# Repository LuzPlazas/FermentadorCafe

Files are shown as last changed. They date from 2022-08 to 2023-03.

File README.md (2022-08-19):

# FermentadorCafe
Códigos asociados al monitor de fermentación de café
-----------

DESARROLLO DE UN SISTEMA PARA EL MONITOREO INTELIGENTE DEL PROCESO DE FERMENTACIÓN DEL CAFÉ 

LUZ ADRIANA PLAZAS PEMBERTHY
CÓDIGO 2190651

UNIVERSIDAD AUTÓNOMA DE OCCIDENTE
2022

------------------------------
Código generado en el desarrollo de un sistema de monitoreo inteligente del proceso de fermentación del café para facilitarle al caficultor la producción de diferentes perfiles de café.

* Se encuentra el firmware para Arduino para la lectura y procesamiento de sensores.
* Se encuentra el software para Raspberry desarrollado en python para almacenamiento y análisis de datos.
* Se encuentran los códigos para entrenamiento de los modelos de aprendizaje automático y los dataset asociados en formato csv.

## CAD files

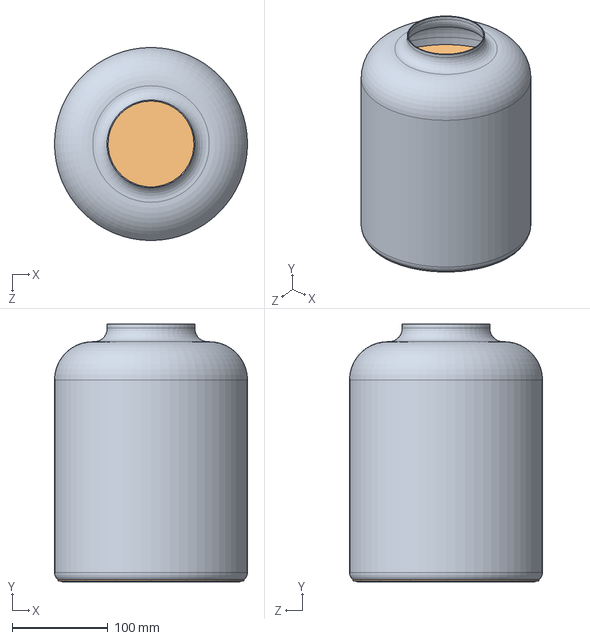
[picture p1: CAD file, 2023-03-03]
MF-A002-V1/MF-E001.SLDASM
202.0 x 270.0 x 202.0 mm
e1

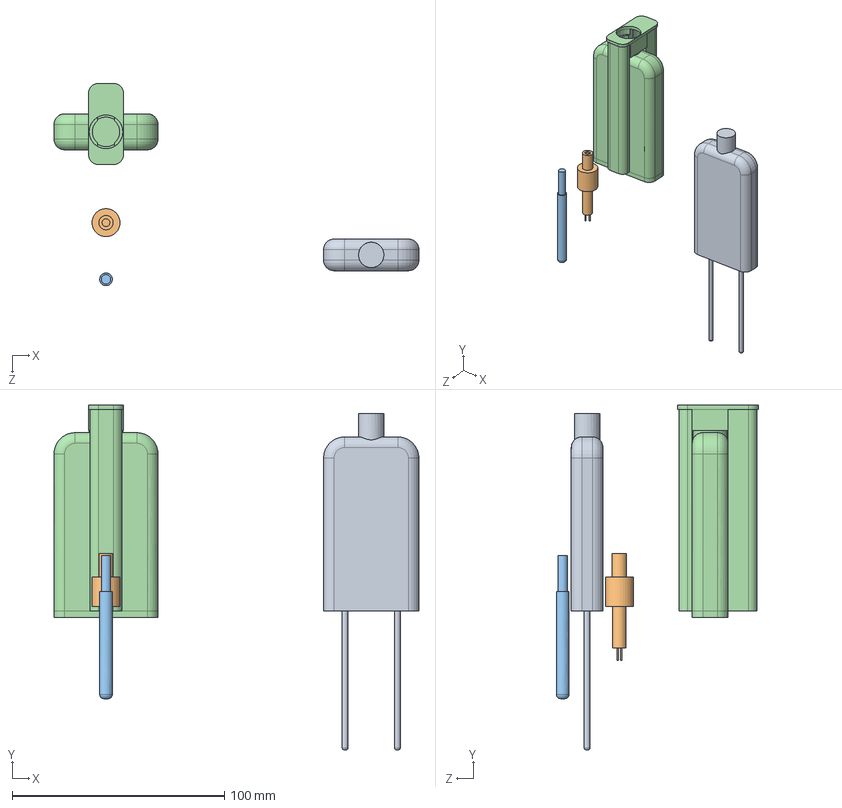
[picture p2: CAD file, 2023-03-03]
MF-A002-V1/Assem3.SLDASM
171.9 x 162.5 x 95.3 mm
MF-P009
MF-P010
MF-P011

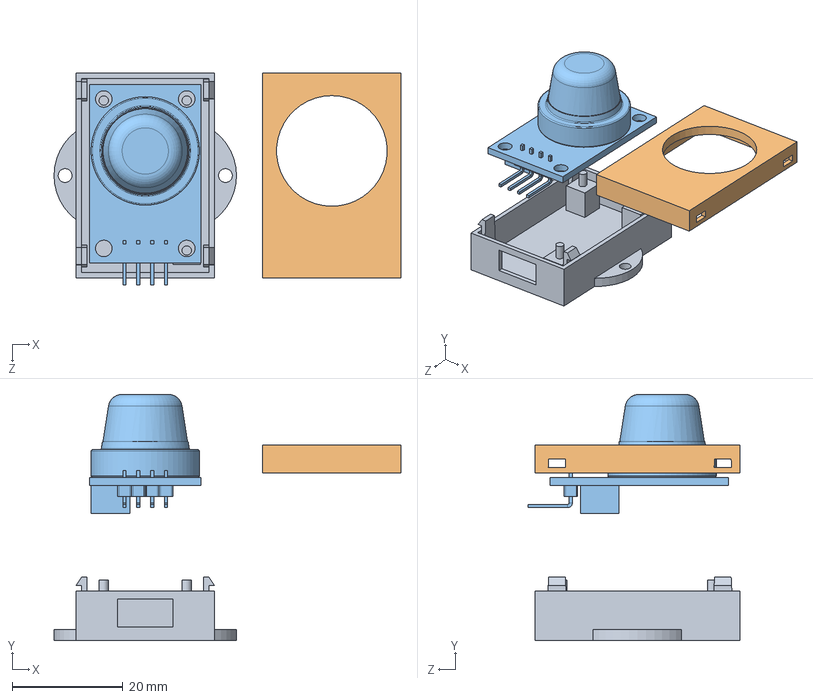
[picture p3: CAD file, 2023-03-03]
MF-A002-V1/s2.SLDASM
62.7 x 44.5 x 38.3 mm
MF-P022
MF-P023
MF-P020

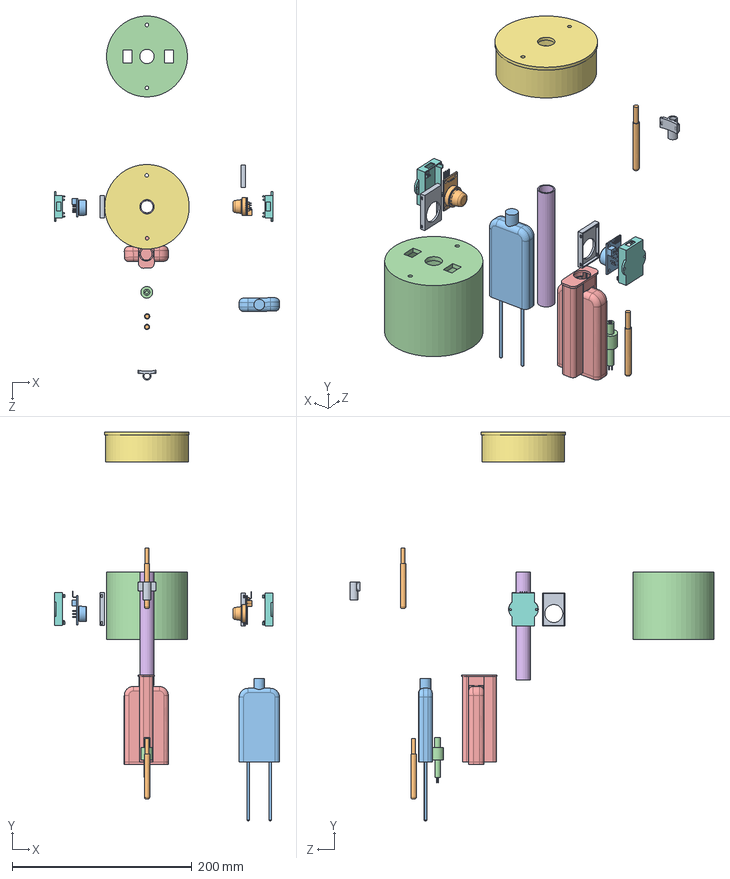
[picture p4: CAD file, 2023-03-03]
MF-A002-V1/MF-B001.SLDASM
250.4 x 432.3 x 404.8 mm
MF-P019b
MF-P011 x 2
MF-P009
MF-P010
MF-P022 x 2
MF-P023 x 2
MF-P020
MF-P021
Part1-B

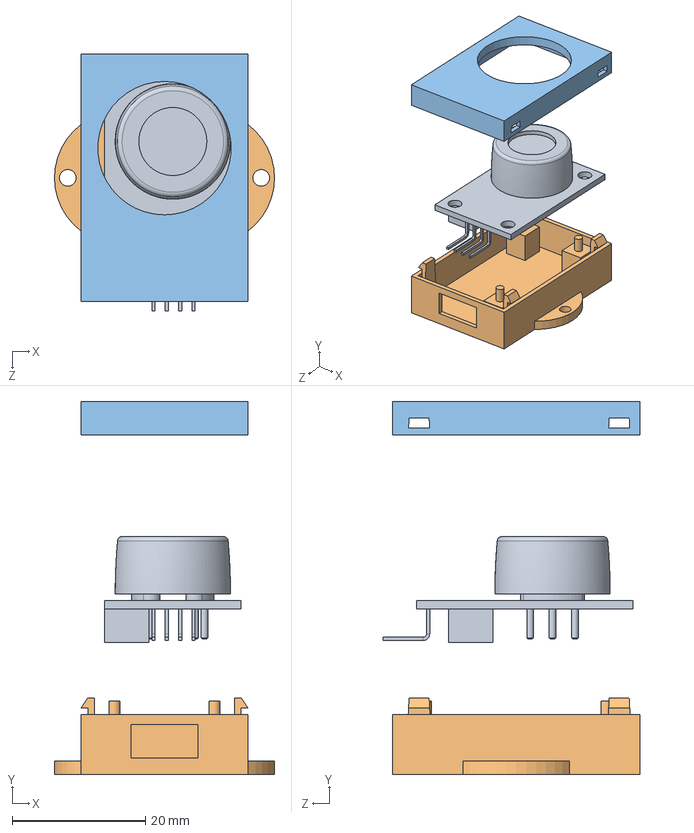
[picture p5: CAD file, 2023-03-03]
MF-A002-V1/s1.SLDASM
33.0 x 55.9 x 38.5 mm
MF-P021
MF-P022
MF-P023

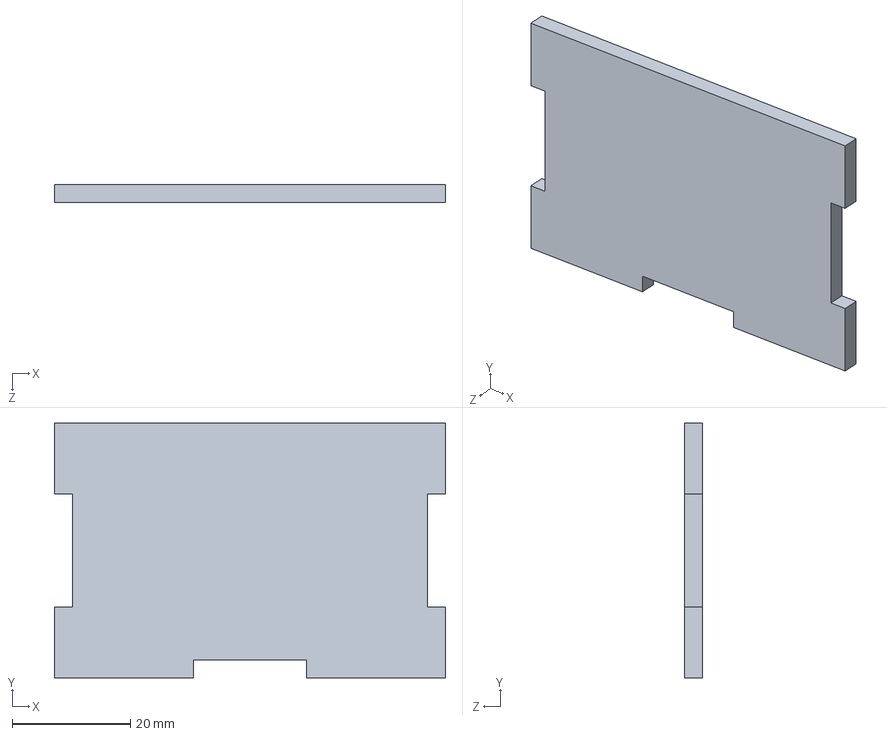
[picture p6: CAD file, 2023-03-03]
MF-A002-V1/front.SLDPRT
66.0 x 43.0 x 3.00 mm

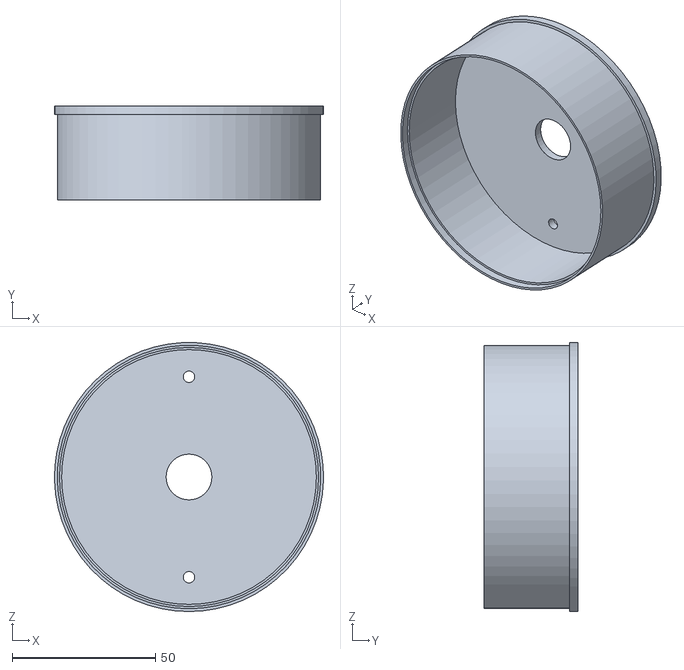
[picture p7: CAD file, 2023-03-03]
MF-A002-V1/Imprimir/Part4.STL
94.0 x 33.0 x 94.0

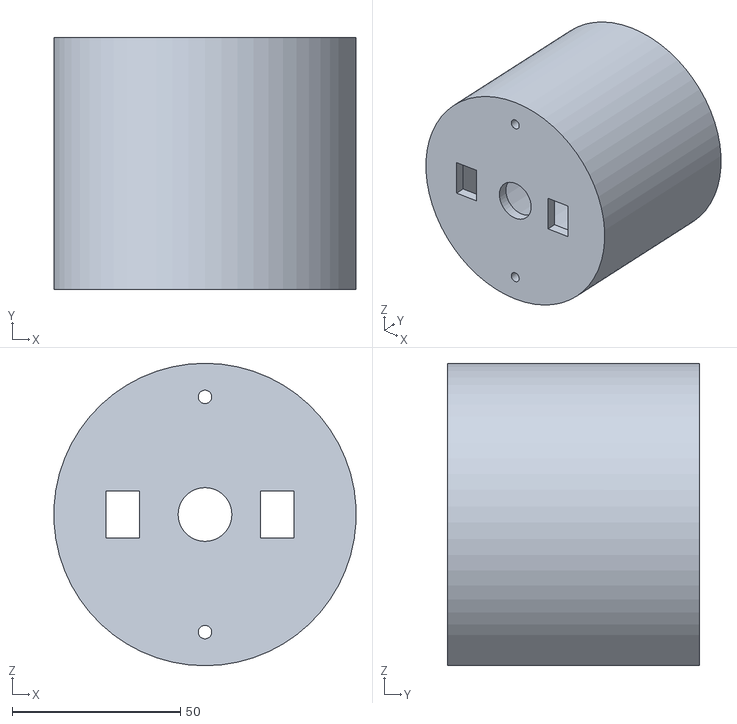
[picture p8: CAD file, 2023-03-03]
MF-A002-V1/Imprimir/Part1-B.STL
89.9 x 75.0 x 90.0

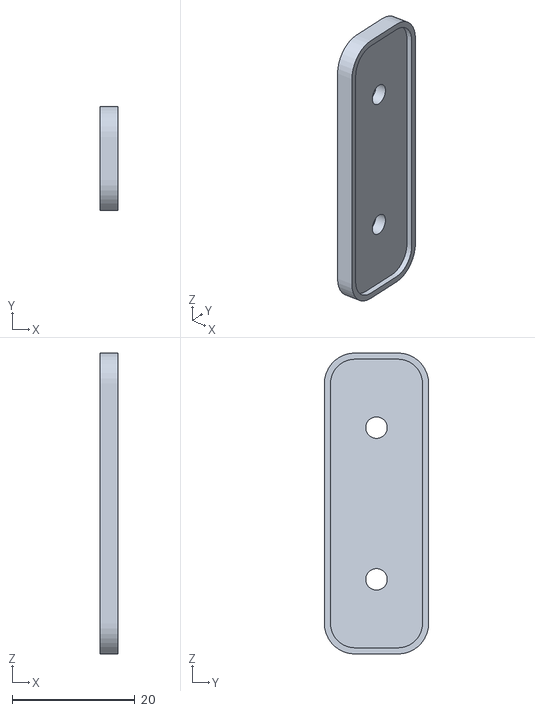
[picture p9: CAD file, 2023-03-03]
MF-A002-V1/Imprimir/Part6-inf.STL
3.00 x 17.0 x 49.0

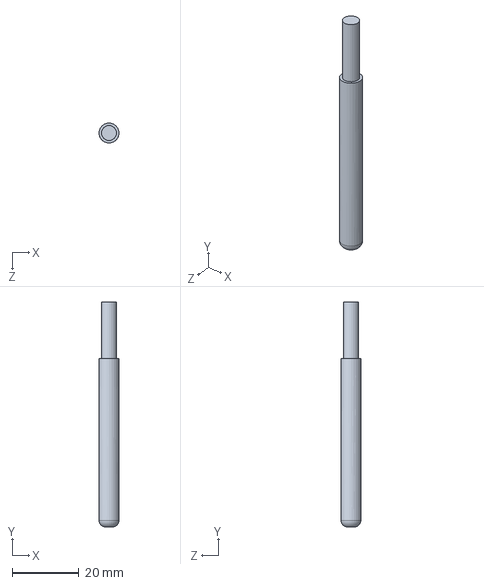
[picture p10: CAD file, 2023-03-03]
MF-A002-V1/MF-P011.SLDPRT
6.00 x 67.5 x 6.00 mm

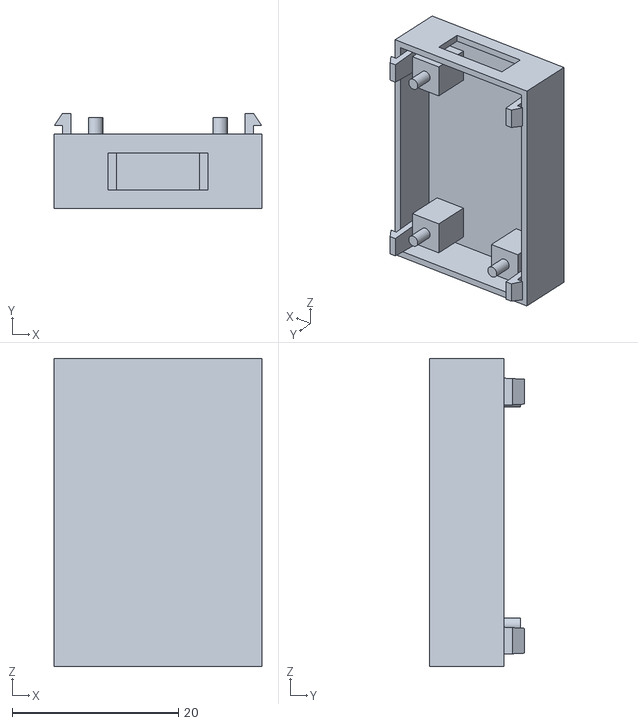
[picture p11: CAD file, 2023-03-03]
MF-A002-V1/Imprimir/MF-P022.STL
25.0 x 11.5 x 37.1

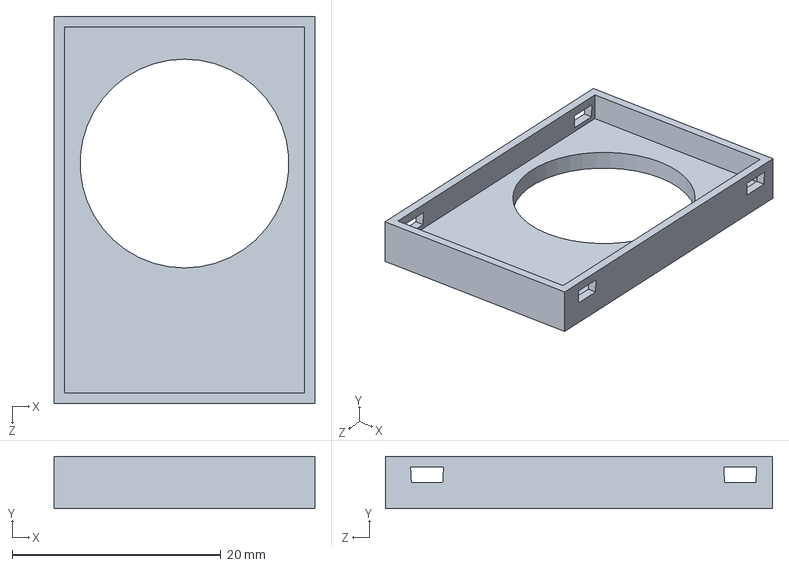
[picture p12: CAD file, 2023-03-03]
MF-A002-V1/MF-P023.SLDPRT
25.0 x 5.00 x 37.1 mm

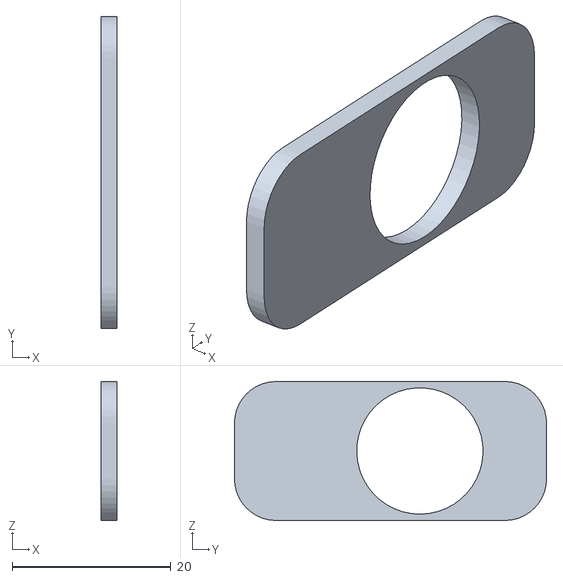
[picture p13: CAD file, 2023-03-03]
MF-A002-V1/Imprimir/Part6-sup.STL
2.00 x 39.3 x 17.5

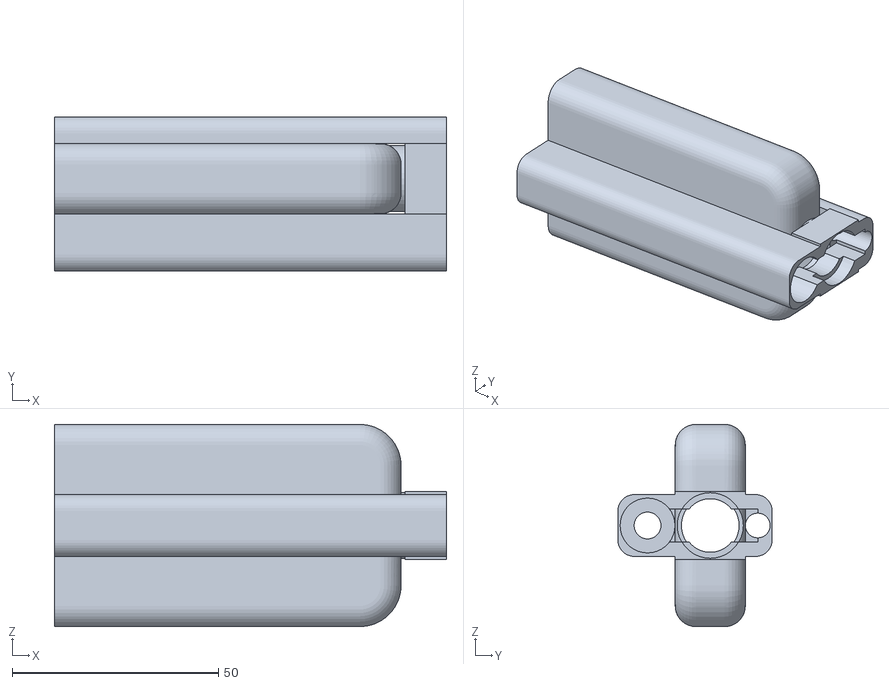
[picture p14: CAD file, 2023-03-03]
MF-A002-V1/Imprimir/Part6-cuerpo.STL
95.0 x 37.4 x 49.0

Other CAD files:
MF-A002-V1/Part4.SLDPRT
MF-A002-V1/MF-P008.SLDPRT
MF-A002-V1/Imprimir/MF-P023.STL
MF-A002-V1/MF-P013-v2.SLDPRT
MF-A002-V1/Imprimir/Part5.STL
MF-A002-V1/MF-P007.SLDPRT
MF-A002-V1/MF-P009.SLDPRT
MF-A002-V1/MF-P010.SLDPRT
MF-A002-V1/MF-P012.SLDPRT
MF-A002-V1/MF-P014.SLDPRT
MF-A002-V1/MF-P015.SLDPRT
MF-A002-V1/MF-P019.SLDPRT
MF-A002-V1/MF-P019b.SLDPRT
MF-A002-V1/MF-P020.SLDPRT
MF-A002-V1/MF-P021.SLDPRT
MF-A002-V1/MF-P022.SLDPRT
MF-A002-V1/Part1-B.SLDPRT
MF-A002-V1/Part1.SLDPRT
MF-A002-V1/Part2.SLDPRT
MF-A002-V1/Part5.SLDPRT
MF-A002-V1/Part6.SLDPRT
MF-A002-V1/botom.SLDPRT
MF-A002-V1/e1.SLDPRT
MF-A002-V1/lock.SLDPRT
MF-A002-V1/right.SLDPRT
MF-A002-V1/tapa.SLDPRT

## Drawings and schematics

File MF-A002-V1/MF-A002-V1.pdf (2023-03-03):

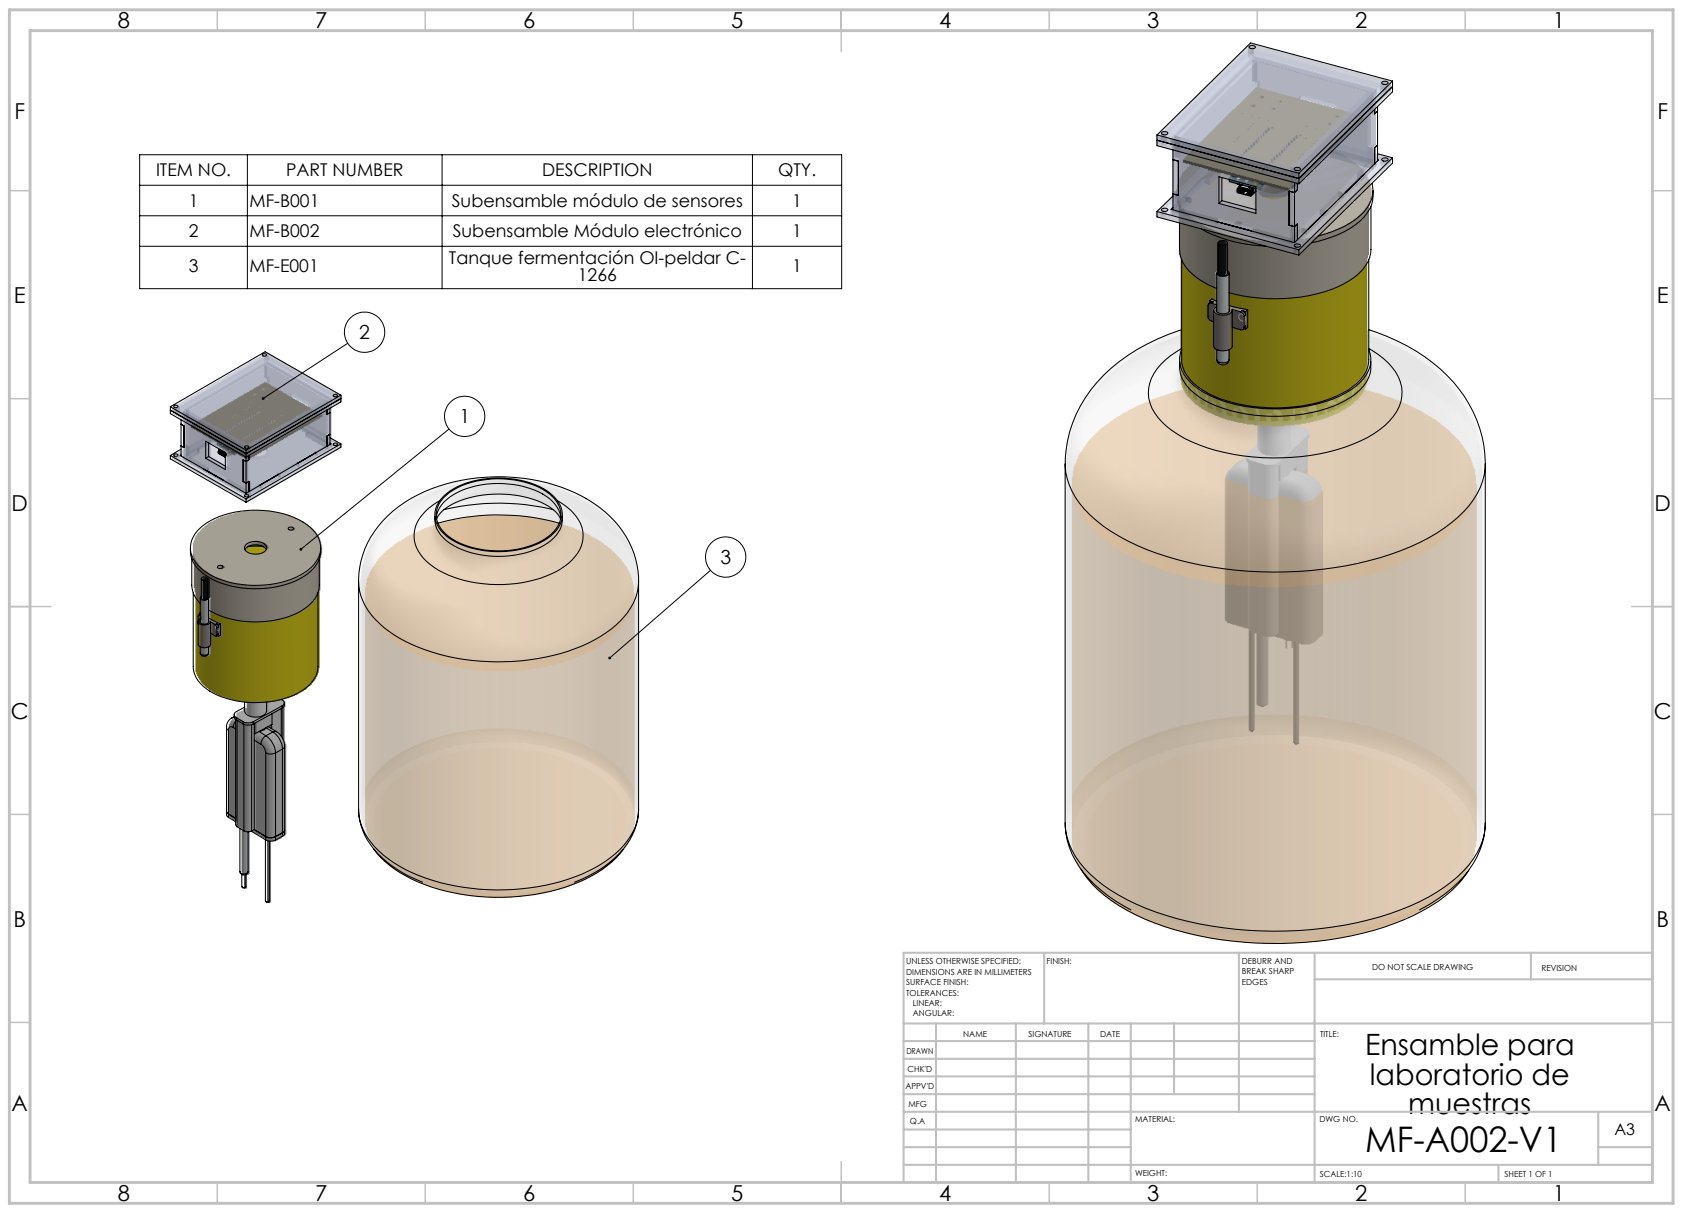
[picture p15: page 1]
FINISH:; DEBURR AND; BREAK SHARP; DO NOT SCALE DRAWING; REVISION; SCALE:1:10; SHEET 1 OF 1

ITEM NO. | PART NUMBER | DESCRIPTION | QTY.
1 | MF-B001 | Subensamble módulo de sensores | 1
2 | MF-B002 | Subensamble Módulo electrónico | 1
3 | MF-E001 | Tanque fermentación OI-peldar C-1266 | 1

UNLESS OTHERWISE SPECIFIED:
DIMENSIONS ARE IN MILLIMETERS
SURFACE FINISH:
TOLERANCES:
LINEAR:
ANGULAR:

NAME | SIGNATURE | DATE | | | | Ensamble para TITLE: laboratorio de muestras

DRAWN
CHK'D
APPV'D
MFG
Q.A | | | | MATERIAL: | DWG NO. MF-A002-V1 | A3

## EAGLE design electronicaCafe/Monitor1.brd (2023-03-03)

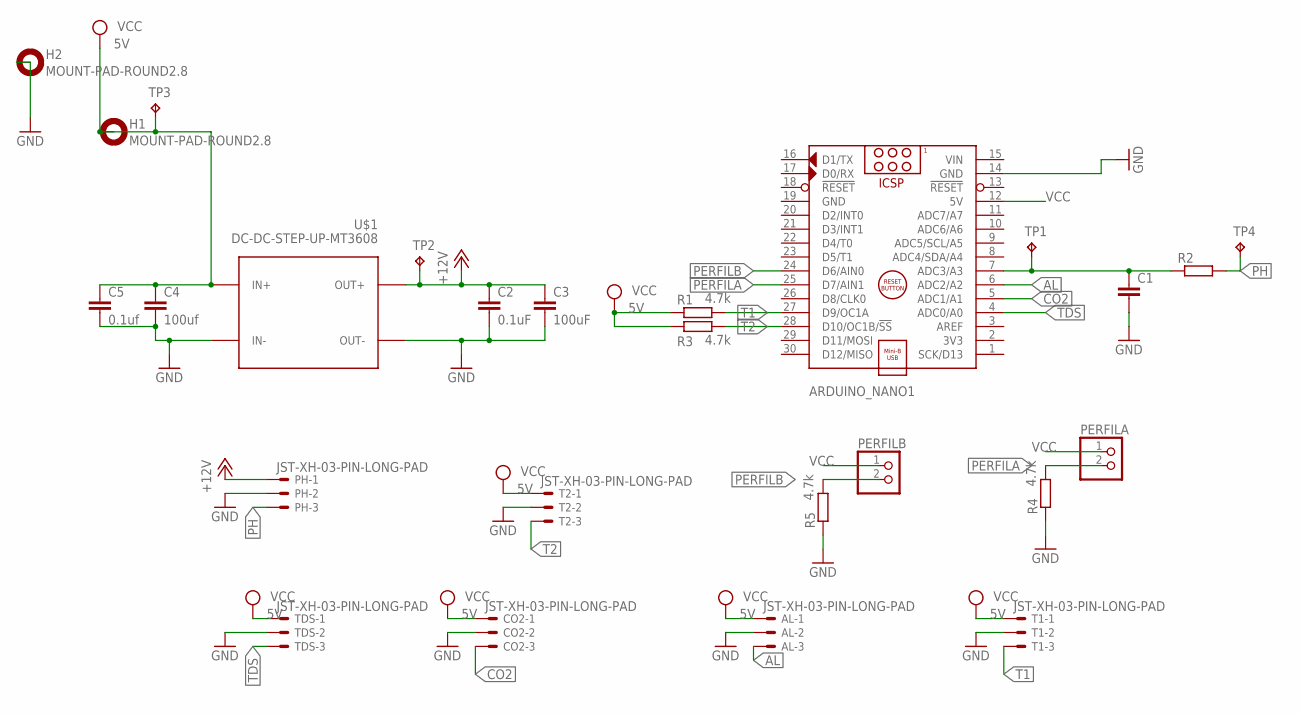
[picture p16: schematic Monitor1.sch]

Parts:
AL: JST-XH-03-PIN-LONG-PAD; JST-XH-03-PACKAGE-LONG-PAD
ARDUINO_NANO1: ARDUINO_NANO
C1: C-EU050-030X075; C050-030X075
C2: 0.1uF; C050-030X075
C3: 100uF; C050-045X075
C4: 100uf; C050-045X075
C5: 0.1uf; C050-030X075
CO2: JST-XH-03-PIN-LONG-PAD; JST-XH-03-PACKAGE-LONG-PAD
H1, H2: MOUNT-PAD-ROUND2.8; 2,8-PAD
PERFILA: PINHD-1X2; 1X02
PERFILB: PINHD-1X2; 1X02
PH: JST-XH-03-PIN-LONG-PAD; JST-XH-03-PACKAGE-LONG-PAD
R1, R3, R4, R5: 4.7k; 0309/10
R2: R-EU_0309/10; 0309/10
T1, T2: JST-XH-03-PIN-LONG-PAD; JST-XH-03-PACKAGE-LONG-PAD
TDS: JST-XH-03-PIN-LONG-PAD; JST-XH-03-PACKAGE-LONG-PAD
TP1, TP2, TP3, TP4: TPPAD1-13; P1-13
U$1: DC-DC-STEP-UP-MT3608

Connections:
+12V: C2.1, C3.1, PH.1, TP2.TP, U$1.OUT+
AL: AL.3, ARDUINO_NANO1.6 (ADC2/A2)
CO2: ARDUINO_NANO1.5 (ADC1/A1), CO2.3
GND: AL.2, ARDUINO_NANO1.14 (GND), ARDUINO_NANO1.19 (GND), C1.2, C2.2, C3.2, C4.2, C5.2, CO2.2, H2.B2,8, PH.2, R4.1, R5.1, T1.2, T2.2, TDS.2, U$1.IN-, U$1.OUT-
unnamed: ARDUINO_NANO1.7 (ADC3/A3), C1.1, R2.1, TP1.TP
PERFILA: ARDUINO_NANO1.25 (D7/AIN1), PERFILA.2, R4.2
PERFILB: ARDUINO_NANO1.24 (D6/AIN0), PERFILB.2, R5.2
PH: PH.3, R2.2, TP4.TP
T1: ARDUINO_NANO1.27 (D9/OC1A), R1.2, T1.3
T2: ARDUINO_NANO1.28 (D10/OC1B/!SS), R3.2, T2.3
TDS: ARDUINO_NANO1.4 (ADC0/A0), TDS.3
VCC: AL.1, ARDUINO_NANO1.12 (5V), C4.1, C5.1, CO2.1, H1.B2,8, PERFILA.1, PERFILB.1, R1.1, R3.1, T1.1, T2.1, TDS.1, TP3.TP, U$1.IN+
VIN: ARDUINO_NANO1.15 (VIN)

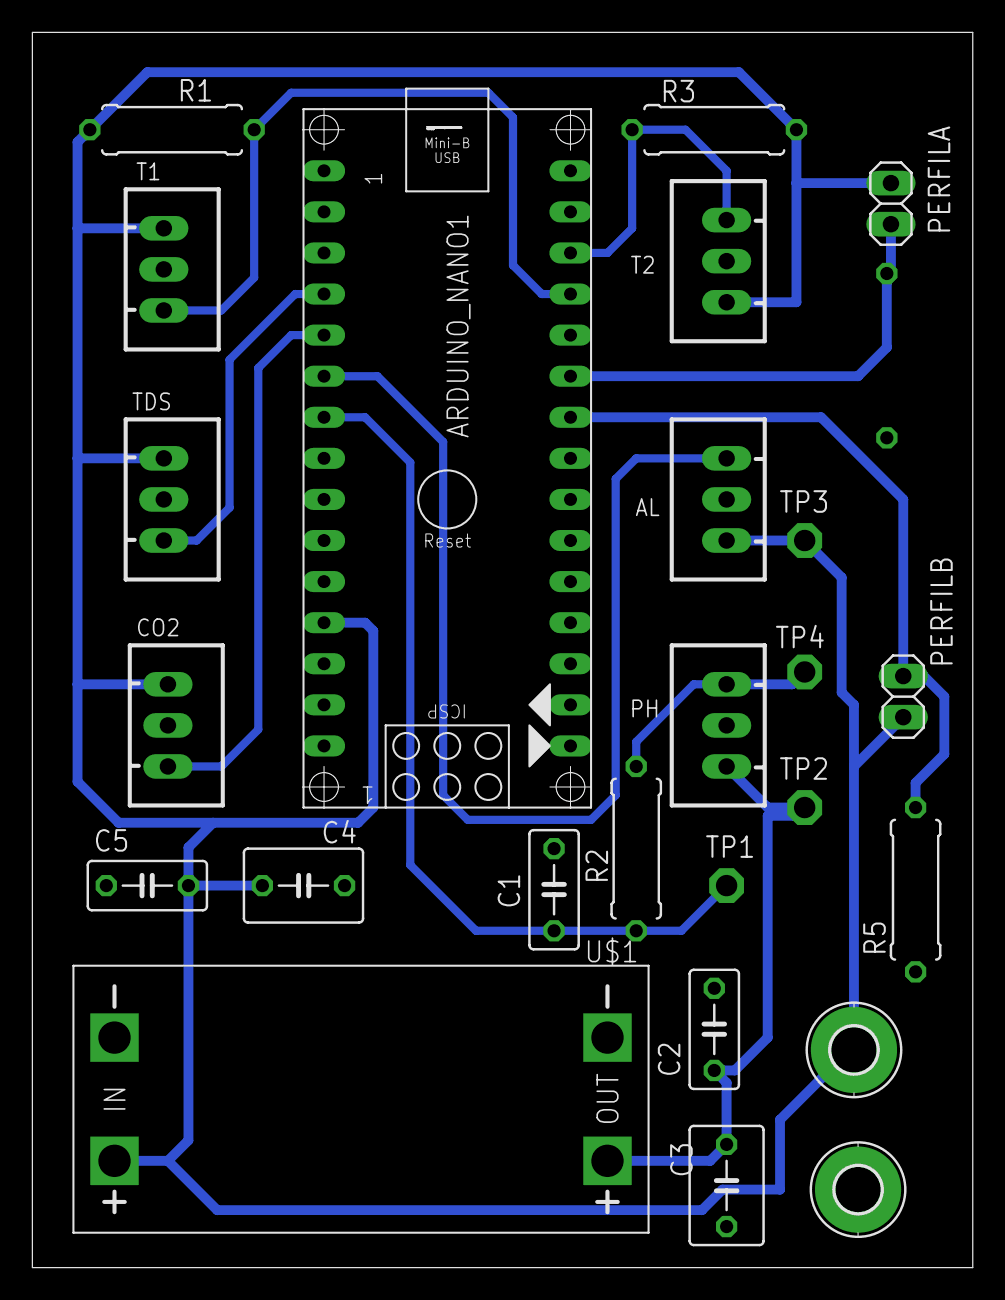
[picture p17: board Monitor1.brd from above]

Board: 2 copper layers, 58.1 x 76.4 mm, 26 parts (1 on the bottom side), 12 nets.

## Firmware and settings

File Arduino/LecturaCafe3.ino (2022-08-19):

#include <OneWire.h>
#include <DallasTemperature.h>
#include <movingAvg.h>

#define pinA 7
#define pinB 6

int sensorAlcohol = 0;
int sensorPH = 0;
int PHfiltrado = 0;
int sensorTDS = 0;
int TDSfiltrado = 0;
int sensorCO2 = 0;
float Temp1=0;
float Temp2=0;
byte perfilA=0;
byte perfilB=0;
int datoPerfil=0;

//

long PorcAl =0;

// GPIO where the DS18B20 is connected to
const int oneWireBus = 9;
const int twoWireBus = 10; 

// Setup a oneWire instance to communicate with any OneWire devices
OneWire oneWire(oneWireBus);
OneWire twoWire(twoWireBus);

// Pass our oneWire reference to Dallas Temperature sensor 
DallasTemperature sensorT1(&oneWire);
DallasTemperature sensorT2(&twoWire);
//
float EMA_ALPHA = 0.2;//MENOR ES EL NUMERO MAYOR FILTRADO Y ATENUACIÓN
float EMA_LP = 0;
//
float EMA_ALPHA2 = 0.5;//MENOR ES EL NUMERO MAYOR FILTRADO Y ATENUACIÓN
float EMA_LP2 = 0;

//
//long SampleTime = 60000; //ms
long SampleTime = 5000; //ms
//long SampleTime = 30000; //ms
unsigned long lastTime = 0;


//moving average para ph
movingAvg avgPH(200);  

void setup() {
  // put your setup code here, to run once:
  Serial.begin(19200);  //9600 19200 o 115200
  pinMode(13, OUTPUT);
  digitalWrite(7, LOW); 
  pinMode(pinA, INPUT);//perfilA
  pinMode(pinB, INPUT);//perfilB

  
  // Start the DS18B20 sensor
  sensorT1.begin();//inicias el sensor de temp1
  sensorT1.setResolution(12);
  sensorT2.begin();
  sensorT2.setResolution(12);

   avgPH.begin();                            // initialize the moving average
}

void loop() {


  if (datoPerfil==0)
  {
  selectPerfil();
  }
  
  sensorTDS = analogRead(A0);
  sensorCO2 = analogRead(A1);
  sensorAlcohol = analogRead(A2);
  sensorPH = analogRead(A3);

  TDSfiltrado = EMALowPassFilter2(sensorTDS);

  PHfiltrado  = avgPH.reading(sensorPH); 
  ReadDS18B20();
  unsigned long now = millis();
  long timeChange = (now - lastTime);


  // Determina si hay que ejecutar el PID o retornar de la función.
  if (timeChange >= SampleTime)
  {  
   Serial.println(String(TDSfiltrado)+","+String(sensorCO2)+","+String(sensorAlcohol)+","+String(PHfiltrado)+","+String(Temp1)+","+String(Temp2)+","+String(datoPerfil));
   lastTime = now;
  }
}

// Lectura Temperaturas
void ReadDS18B20()
{
  sensorT1.requestTemperatures(); 
  Temp1 = sensorT1.getTempCByIndex(0);
  //Serial.print(temperatureC);
  //Serial.println("ºC");
  delay(2000);//retardo ms
  
  sensorT2.requestTemperatures(); 
  Temp2 = sensorT2.getTempCByIndex(0);
  Temp2= Temp2-1;
  //Serial.print(temperatureC_2);
  //Serial.println("ºC");
  delay(2000);//retardo ms
}
void selectPerfil(){
  perfilA = digitalRead(pinA);
  perfilB = digitalRead(pinB);
  
  if(perfilA==0 && perfilB==0)
    datoPerfil = 0;
  else if(perfilA==0 && perfilB==1)
    datoPerfil = 1;
  else if(perfilA==1 && perfilB==0)
    datoPerfil = 2;
  else if(perfilA==1 && perfilB==1)
    datoPerfil = 3;    
}

//FUNCION FILTRADO
float EMALowPassFilter(float value)
{
  EMA_LP = EMA_ALPHA * value + (1 - EMA_ALPHA) * EMA_LP;
  return EMA_LP;
}

float EMALowPassFilter2(float value)
{
  EMA_LP2 = EMA_ALPHA2 * value + (1 - EMA_ALPHA2) * EMA_LP2;
  return EMA_LP2;
}

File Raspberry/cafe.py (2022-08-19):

import RPi.GPIO as GPIO #Librer?a para controlar GPIO
#sudo apt-get install python3-serial  ó pip install serial
import serial
import os
#import Arduino~
#sudo apt-get  install python3-pandas
import pandas as pd
#sudo apt-get install csv python3  ó  sudo pip3 install python-csv
import csv
#sudo apt-get  install python3-numpy
import numpy as np
from time import strftime, localtime, asctime

from datetime import time as tm
from datetime import datetime, date, timedelta
#	sudo apt install python3-picamera
                #from picamera import PiCamera
from time import sleep
arduino = serial.Serial('/dev/ttyUSB0',19200)
#arduino = serial.Serial('/dev/ttyUSB0',9600) 
arduino.setDTR(False)
sleep(1)
arduino.flushInput()
arduino.setDTR(True)
nombreA=asctime(localtime())
  
GPIO.setmode(GPIO.BCM) #Simplemente nos sirve para usar n?meros de pin de placa y no del procesador
GPIO.setwarnings(False) #Con esto impedimos que nos aparezcan warnings que en este caso no ser?n importantes
led = 21 #Variable donde ponemos el pin que usaremos para el LED
GPIO.setup(led, GPIO.OUT) #Configuramos el pin 21 (led) como salida
GPIO.output(led,0) #Apagado el LED
led2 = 16 #Variable donde ponemos el pin que usaremos para el LED
GPIO.setup(led2, GPIO.OUT) #Configuramos el pin 16 (led2) como salida
GPIO.output(led2,0) #Apagado el LED

PHprom = 0
cont = 0
maxCO2 = 0
ALprom = 0
DT1prom = 0
DT2prom = 0
TDSprom = 0
minT2 = 100
DCO2prom = 0
DALprom = 0
Samples = 1440
flagS = 10
umbralCal = 7.5
dataCalprom = 0
flagcalprom = 0

TD = []
C= []
A = []
P = []
t1 = []
t2 = []
t = []
Q = []
fcalidad = []
contC =[]
derivT1 = []
derivCO2 = []
derivAL = []
derivT2 = []
calp = []
dataD = {}
vmedianaPH = []
vDCO2prom = []
vDALprom = []
vDT1prom = []
vDT2prom = []
vdesvTDS = []

vPHprom = []
vmaxCO2 = []
vALprom = []

vTDSprom = []
vminT2 = []


def promedio(datop,dato,c):
    datop = (datop*(c-1)+dato)/c;
    print("Prom: "+str(datop))
    return datop
def maximo(maxdato,dato):
    if maxdato < dato:
        maxdato = dato
    print("Max: "+str(maxdato))
    return maxdato
def minimo(mindato,dato):
    if mindato > dato:
        mindato = dato
    print("Min: "+str(mindato))
    return mindato
def derivada(deriv,S,c):
    deltaD=0
    if c == 1:
        #datoprev = S.pop(c-1)
        deriv.append(0)
    elif c > 1:
        deltaD = S[c-1]-S[c-2]
        #datoprev = dato
        deriv.append(deltaD)
    print("derivada: "+str(deltaD))
    return deltaD
def calcPerfil1(v1,v2,v3,v4,v5,v6,v7):#aroma
    b = 7.2010438424
    a1 = 0.0001870258
    a2 = -0.0002191831
    a3 = -6.98251646
    a4 = 3.30947832
    a5 = -109.077613
    a6 = -92.8057011
    a7 = -0.003117922
    calcP = b+a1*v1+a2*v2+a3*v3+a4*v4+a5*v5+a6*v6+a7*v7
    return calcP
def calcPerfil2(v1,v2,v3,v4,v5):#sabor
    b = 7.5329376768
    a1 = 0.0002070077
    a2 = 0.0001116647
    a3 = -0.0013390289
    a4 = -0.0008735337
    a5 = -24.7612518
    calcP = b+a1*v1+a2*v2+a3*v3+a4*v4+a5*v5
    return calcP
def calcPerfil3(v1,v2,v3,v4,v5,v6,v7):
    b = 4.64572458
    a1 = 0.0006864619
    a2 = 0.0000217523
    a3 = 0.0043348547
    a4 = 0.0008353074
    a5 = -33.4051880
    a6 = 2.77220284
    a7 = 0.003013541
    calcP = b+a1*v1+a2*v2+a3*v3+a4*v4+a5*v5+a6*v6+a7*v7
    return calcP
def promCalidad(cal,c):
    prom=0.0;
    for i in range (c-(Samples+flagS+1),c-(Samples+1),1):
        prom = cal[i]+prom
    prom = prom/flagS
    return prom

try:
  while True:
     GPIO.output(led,0) #Encendemos el LED
     lineBytes = arduino.readline()
     line = lineBytes.decode('utf-8').strip()
     print(line)
     # Separamos los datos recibidos mediante el seprador "|"
     sensorTDS,sensorCO2,porcentajeA,sensorPH,Temp1,Temp2,perfil = line.split(",",7)
     TD.append(int(sensorTDS))
     C.append(int(sensorCO2)) 
     A.append(int(porcentajeA))
     P.append(int(sensorPH))
     t1.append (float(Temp1))
     t2.append (float(Temp2))
     t.append(strftime("%H:%M:%S")) # %Y-%m-%d 
     Q.append(int(perfil))
     tiempo=np.array(t)
     sensor1=np.array(TD)
     sensor2=np.array(C)
     sensor3=np.array(A)
     sensor4=np.array(P)
     sensor5=np.array(t1)
     sensor6=np.array(t2)
     sensor7=np.array(Q)
     
     
     
     cont = cont+1     
     if int(perfil) == 1:
         print("perfil1")
         #pendiente mediana PH
         #deriva de CO2
         deltaCO2 = derivada(derivCO2,C,cont)
         #promedio derivada CO2
         DCO2prom = promedio(DCO2prom,deltaCO2,cont)         
         #deriva de Alcohol
         deltaAL = derivada(derivAL,A,cont)
         #promedio derivada Alcohol
         DALprom = promedio(DALprom,deltaAL,cont)         
         #deriva de Temp1
         deltaT1 = derivada(derivT1,t1,cont)
         dsensorT1=np.array(derivT1)
         #promedio derivada temp1
         DT1prom = promedio(DT1prom,deltaT1,cont)         
         #deriva de Temp2
         deltaT2 = derivada(derivT2,t2,cont)
         #promedio derivada temp2
         DT2prom = promedio(DT2prom,deltaT2,cont)         
         #pendiente desv estandar TDS
         
     elif int(perfil) == 2:
         print("perfil2")
         #promedio acomulado PH
         PHprom = promedio(PHprom,int(sensorPH),cont)
         #maximo CO2
         maxCO2 = maximo(maxCO2,int(sensorCO2))
         #promedio acomulado Alcohol
         ALprom = promedio(ALprom,int(porcentajeA),cont)
         #deriva de Temp1
         deltaT1 = derivada(derivT1,t1,cont)         
         dsensorT1=np.array(derivT1)
         #promedio derivada temp1
         DT1prom = promedio(DT1prom,deltaT1,cont)
         
     elif int(perfil) == 3:
         print("perfil3")
         #promedio acomulado PH
         PHprom = promedio(PHprom,int(sensorPH),cont)
         #promedio acomulado TDS
         TDSprom = promedio(TDSprom,int(sensorTDS),cont)
         #promedio acomulado Alcohol
         ALprom = promedio(ALprom,int(porcentajeA),cont)         
         #deriva de Temp1
         deltaT1 = derivada(derivT1,t1,cont)
         dsensorT1=np.array(derivT1)
         #promedio derivada temp1
         DT1prom = promedio(DT1prom,deltaT1,cont)         
         #deriva de CO2
         deltaCO2 = derivada(derivCO2,C,cont)
         #promedio derivada CO2
         DCO2prom = promedio(DCO2prom,deltaCO2,cont)         
         #minimo T2
         minT2 = minimo(minT2,float(Temp2))     

     data={'tiempo': tiempo,'TDS': sensor1, 'Co2': sensor2, 'Alcohol': sensor3, 'Ph': sensor4, 'Temp1': sensor5, 'Temp2': sensor6, 'Perfil': sensor7 }
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

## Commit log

2023-03-03 Archivos electrónicos
    Archivos de esquemático y PCB para programa EAGLE
    [Monitor1.brd, Monitor1.sch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]
2023-03-03 ARCHIVOS MECANICOS
    Archivos para diseño y fabricación mecánica, para software Solidworks.
    [Assem3.SLDASM, MF-B001.SLDASM, MF-E001.SLDASM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]

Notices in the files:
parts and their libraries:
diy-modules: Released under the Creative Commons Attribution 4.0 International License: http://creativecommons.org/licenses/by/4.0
